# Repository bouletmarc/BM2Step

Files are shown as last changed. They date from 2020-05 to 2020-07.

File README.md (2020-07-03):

# BM2Step
Arduino based 2Step Launch Control Module similar to Bee*R for Honda/Acura

# Compatibility

- All Honda/Acura engines that are 4cylinder and running with a distributor (mainly SerieB, D, F and H engines).
- It does works on Automatics cars.

# Parts List
- 1x Arduino Nano V3 5V 16mhz atmega328p
- 1x 74HC00 Quad 2-input NAND gate (or 74LVC1G00 for a Single gate rather than a Quad gate)
- 2x 2N4401 transistors (2N2222/2N3904 can be used)
- 6x 1K Ohms resistors
- 1x 1 to 10 Ohm resistors (can be replaced with a jumper or '0ohm' directly but a resistor make the circuit safer!)
- 2x B10K Potentiometer 0931
- 2x 2mm to 5mm Leds
- 1x 7805/78M05 5v voltage regulator
- 2x 100nF capacitor (104)
- 1x Diode (minimum of 20v), can be 1N4002, 1N4004, 1N4148, etc..

# Installation

Inputs wires:
- ICM - Ignition Control Module signal from the ECU
- Potentiometer - Launch RPM selection
- Potentiometer - Cut RPM selection
- Activate Launch/2Step (sort to ground to activate)
- 12v Ignition On
- Ground

Outputs wires:
- ICM - Ignition Control Module singal Out for the distributor

**You don't need to power the arduino from the USB, the 7805/78M05 5v regulator output 5v from the 12v Ignition input wire to power the arduino when the Car ignition key are turned On!**

# How to use the BM2Step

1. Choose your desired Launch Control 2Step RPM with the potentiometer
2. Choose your desired Launch Control 2Step Cutting rpm windows with the potentiometer
3. Activate the Launch/2Step by sorting the Activate 'input' to the ground
4. Bring the engine RPM to the desired Launch Control 2Step RPM
5. Enjoy!

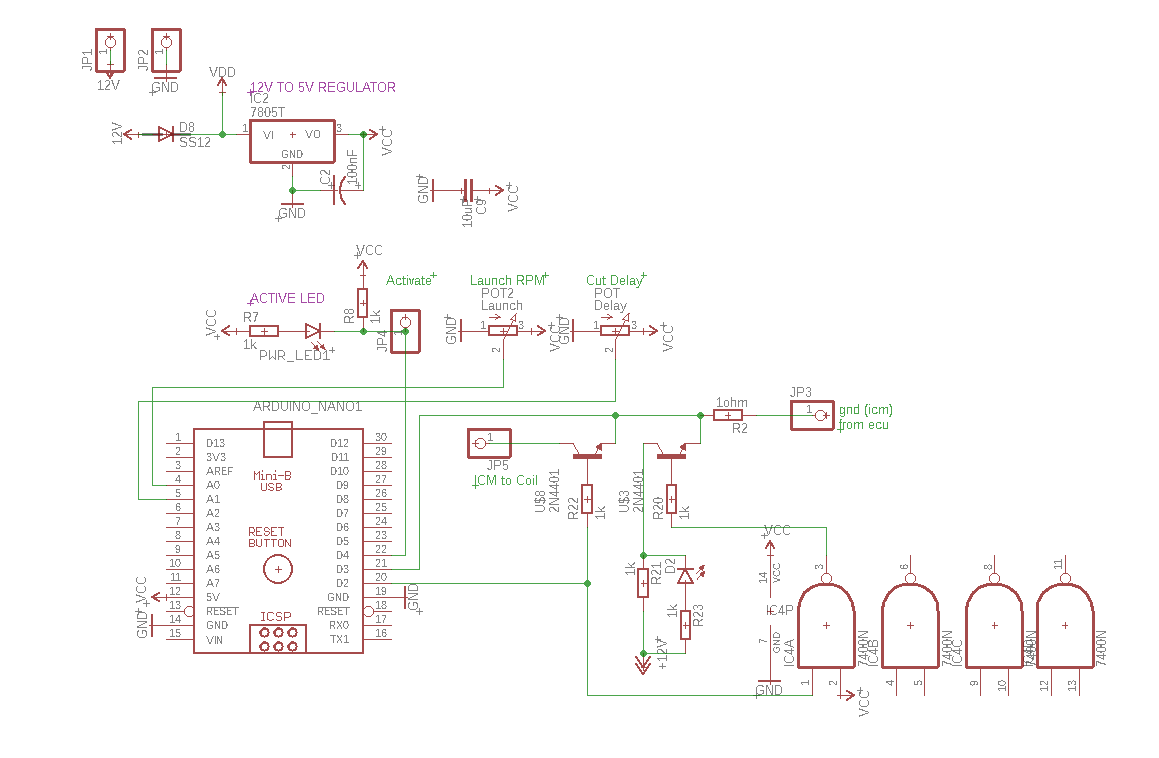
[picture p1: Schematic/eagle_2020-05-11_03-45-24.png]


# How the BM2Step works

The BM2Step works by disabling the ICM ouputs when the BM2Step are active and the engine rpm reach the Set RPM. The diagram have 2x 2n4401 transistors to control the direction of the ICM outputs. One transistor are sending the ICM signal back to the distributor (sending to the ICM ouputs on the BM2Step) while the other transistor are sending the ICM signal in a 'built-in distributor simulator'.

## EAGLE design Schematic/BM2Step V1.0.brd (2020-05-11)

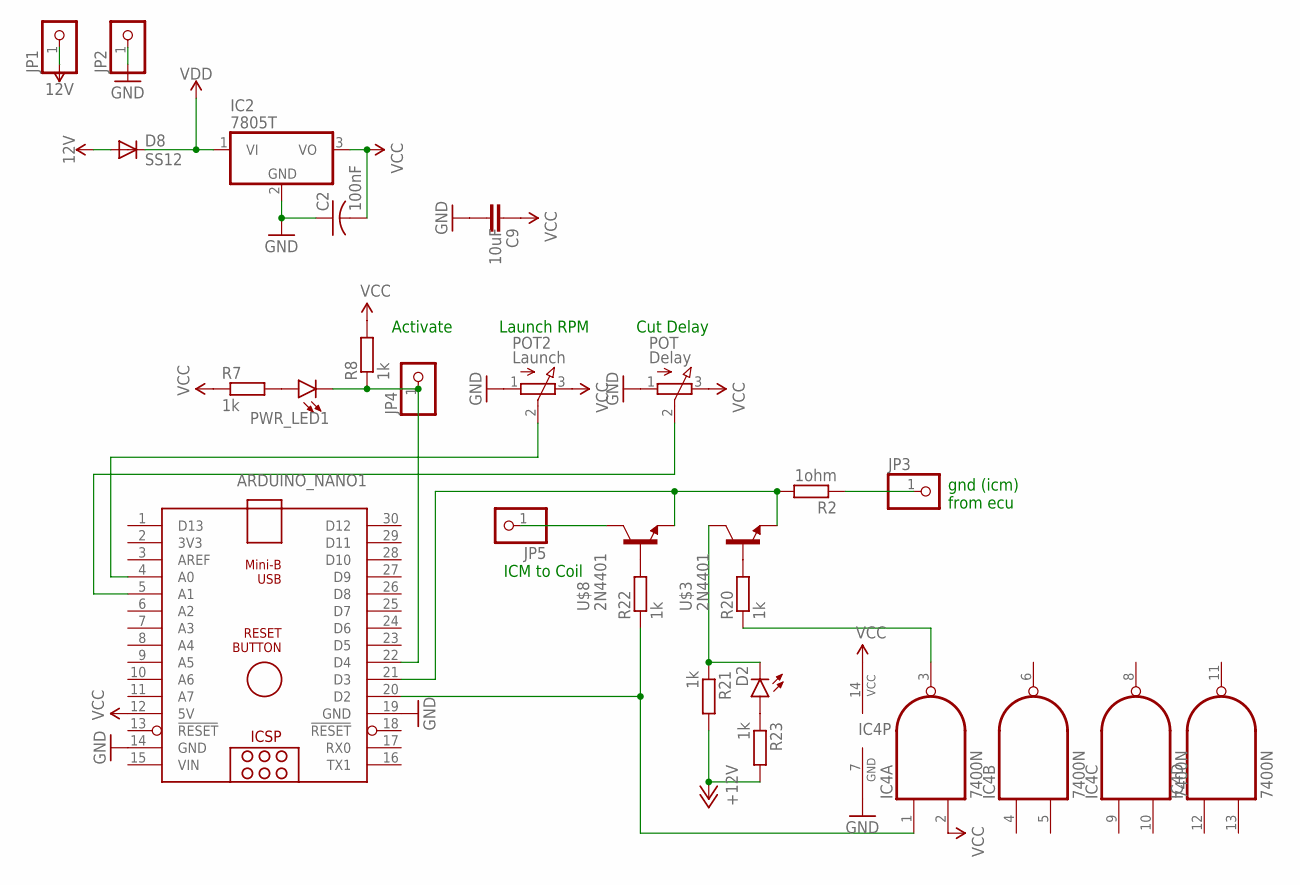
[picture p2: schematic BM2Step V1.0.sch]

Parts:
ARDUINO_NANO1: ARDUINO_NANO
C2: 100nF; C025-024X044
C9: 10uF; AXIAL-5MM
D2: LED3MM
D8: SS12; D-7.5
IC2: 7805T; TO220H
IC4: 7400N; DIL14
JP1, JP2, JP3, JP4, JP5: PINHD-1X1_LARGE; 1X01_LARGE
POT: Delay; EVUF
POT2: Launch; EVUF
PWR_LED1: LED3MM; LED_3MM
R2: 1ohm; 0204/7
R7, R8, R20, R21, R22, R23: 1k; 0204/7
U$3, U$8: 2N4401; TO92-ECB

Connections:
12V: D8.A, JP1.1
+12V: R21.2, R23.2
GND: ARDUINO_NANO1.14 (GND), ARDUINO_NANO1.19 (GND), C2.1, C9.P$2 (2), IC2.2 (GND), IC4.7 (GND), JP2.1, POT.1 (A), POT2.1 (A)
unnamed: IC4.3 (O), R20.1
unnamed: ARDUINO_NANO1.22 (D4), JP4.1, PWR_LED1.K (C), R8.1
unnamed: ARDUINO_NANO1.4 (A0), POT2.2 (S)
unnamed: ARDUINO_NANO1.5 (A1), POT.2 (S)
unnamed: JP3.1, R2.1
unnamed: ARDUINO_NANO1.21 (D3), R2.2, U$3.E, U$8.E
unnamed: PWR_LED1.A, R7.2
unnamed: R20.2, U$3.B
unnamed: D2.K (C), R21.1, U$3.C
unnamed: JP5.1, U$8.C
unnamed: R22.2, U$8.B
unnamed: ARDUINO_NANO1.20 (D2), IC4.1 (I0), R22.1
unnamed: D2.A, R23.1
VCC: ARDUINO_NANO1.12 (5V), C2.2, C9.P$1 (1), IC2.3 (VO), IC4.2 (I1), IC4.14 (VCC), POT.3 (E), POT2.3 (E), R7.1, R8.2
VDD: D8.C, IC2.1 (VI)
VIN: ARDUINO_NANO1.15 (VIN)

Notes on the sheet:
gnd (icm) from ecu
ICM to Coil
Launch RPM
Cut Delay
Activate

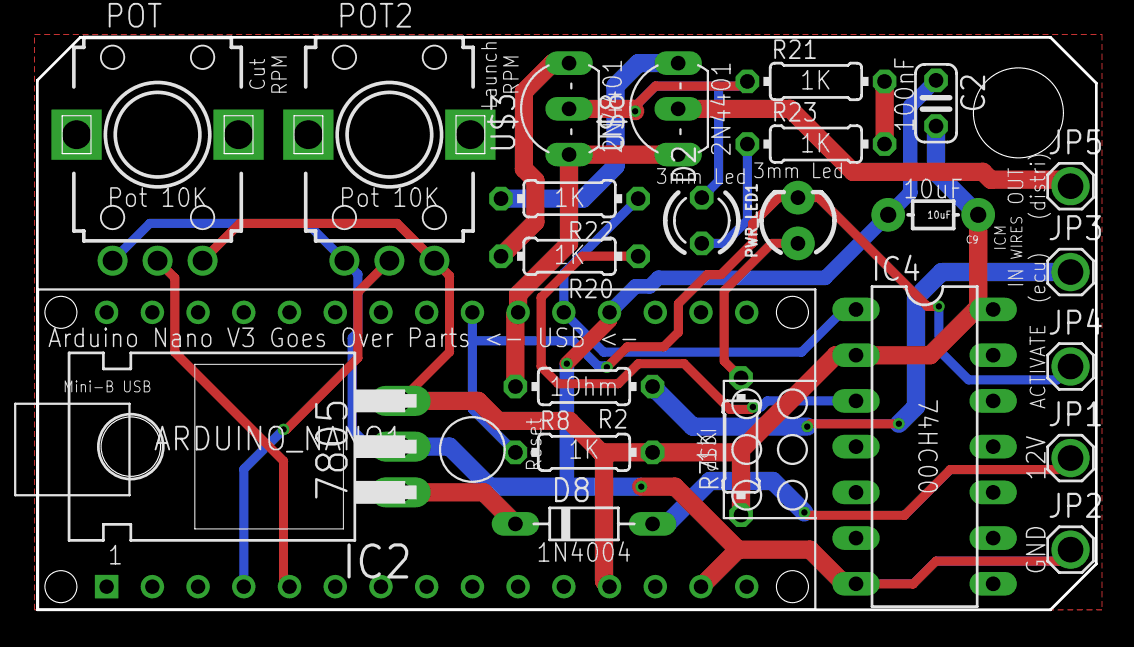
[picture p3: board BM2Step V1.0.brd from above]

Board: 2 copper layers, 58.8 x 31.8 mm, 24 parts (0 on the bottom side), 18 nets.

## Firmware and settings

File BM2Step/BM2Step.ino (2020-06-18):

#include <SPI.h>
#include <Wire.h>
#include "Arduino.h"

int ontime,offtime,duty;
float freq,period;

#define pulse_ip 3
#define Cutting_Output 2
#define Activate_Input 4
#define LaunchRPM_Input A0
#define LaunchDelay_Input A1

#define BAUDRATE  115200

int LaunchRPM = 3500;
int CutRPMWindows = 500;
int CurrentRPM = 0;
int SmoothRPM[] = {0, 0, 0};
int SmoothRPMBuffer[] = {0, 0, 0};
bool Cutting2Step = false;
int PotRpmValue;

void setup() {
  Serial.begin(BAUDRATE);
  
  pinMode(pulse_ip,INPUT);
  pinMode(Cutting_Output, OUTPUT);
  pinMode(LaunchRPM_Input, INPUT);
  pinMode(LaunchDelay_Input, INPUT);
  pinMode(Activate_Input, INPUT);
}

void loop() {
  ontime = pulseIn(pulse_ip,HIGH);
  offtime = pulseIn(pulse_ip,LOW);
  period = ontime+offtime;
  freq = 1000000.0/period;
  duty = (ontime/period)*100;

  if (duty > 0 && duty < 100) {
    CurrentRPM = freq * 30;
    AddToSmooth(CurrentRPM);
    
    GetLaunchRPM();
    GetCutRPM();
    Check2Step();
    
    SerialPrinting();
  }
  else {
    Disable2Step();
    Serial.print("Unknown RPM detected!");
    Serial.println("");
  }

  delay(1);

}

void GetLaunchRPM() {
  PotRpmValue = analogRead(LaunchRPM_Input);
  if (PotRpmValue>203)
  {
    LaunchRPM = map(PotRpmValue, 203, 1023, 4500, 9000);
  }
  else
  {
    if (PotRpmValue>126)
    {
      LaunchRPM = map(PotRpmValue, 127, 203, 3200, 4500);
    }
    else
    {
      LaunchRPM = map(PotRpmValue, 0, 126, 2500, 3200);
    }
  }
  LaunchRPM = (LaunchRPM +24)/25;
  LaunchRPM = LaunchRPM * 25;
}

void GetCutRPM() {
  CutRPMWindows = analogRead(LaunchDelay_Input);
}

void SerialPrinting() {
  Serial.print("Freq:");
  Serial.print(freq);
  Serial.print("Hz");
  
  Serial.print("\tDuty");
  Serial.print(duty);
  Serial.print("%");

  
  Serial.print("\tRPM:");
  Serial.print(GetSmoothRPM());
  //Serial.print(CurrentRPM);

  
  Serial.print("\t2Step:");
  Serial.print(Cutting2Step);
  Serial.print("\tLaunch:");
  Serial.print(LaunchRPM);
  Serial.print("\tCut:");
  Serial.print(CutRPMWindows);
  
  /*Serial.print("\ton");
  Serial.print(ontime);
  Serial.print("\toff");
  Serial.print(offtime);
  Serial.print("\ttime");
  Serial.print(period);*/
  
  Serial.println("");
}

void Check2Step() {
  bool CanLaunch = false;
  if (digitalRead(Activate_Input) == LOW) {
    CanLaunch = true;
  }

  if (CanLaunch) {
    if (GetSmoothRPM() > LaunchRPM && !Cutting2Step) {
    //if (CurrentRPM > LaunchRPM && !Cutting2Step) {
      Cutting2Step = true;
      digitalWrite(Cutting_Output, HIGH);
    }
    if (GetSmoothRPM() < LaunchRPM - CutRPMWindows && Cutting2Step) {
    //if (CurrentRPM < LaunchRPM - CutRPMWindows && Cutting2Step) {
      Cutting2Step = false;
      digitalWrite(Cutting_Output, LOW);
    }
  } else {
    Cutting2Step = false;
    digitalWrite(Cutting_Output, LOW);
  }
}

void Disable2Step() {
  
    Cutting2Step = false;
    digitalWrite(Cutting_Output, LOW);
}

void AddToSmooth(int AddThisRPM) {
  for (int i = 0; i < 3; i++) {
    SmoothRPMBuffer[i] = SmoothRPM[i];
  }

  SmoothRPM[0] = AddThisRPM;
  
  for (int i = 0; i < 2; i++) {
    SmoothRPM[i+1] = SmoothRPMBuffer[i];
  }
}

int GetSmoothRPM() {
  int TotalRPM = 0;
  for (int i = 0; i < 3; i++) {
    TotalRPM += SmoothRPM[i];
  }

  return TotalRPM / 3;
}

//#########################################################
//#########################################################
//#########################################################
//#########################################################


/*#define rpmPin 2
#define outputRPM 3
#define potPinDelay A0
#define potPinRPM1 A1
#define Activate 6

const int refreshRate = 10;

unsigned int cuttingDelay = 60;
unsigned int cuttingRPM1 = 6000;
unsigned int cuttingRPM2 = 4500;
volatile int revs = 0;
unsigned long rpm = 0;
unsigned long lastmillis = 0;
unsigned long lastmillisCutting = 0;
bool CuttingLimiter = false;
bool CanLaunch = false;


int SmoothSize = 50;
int SmoothingRPM[50];
int CurrentSmooth = 0;


void setup() {
  Serial.begin(115200);
   
  pinMode(Activate, INPUT);
  pinMode(rpmPin, INPUT);
  pinMode(outputRPM, OUTPUT);
  attachInterrupt(digitalPinToInterrupt(rpmPin), rpm_engine, FALLING);
}

void loop() {
  if (digitalRead(Activate) == LOW) {
    CanLaunch = true;
  }
  else {
    CanLaunch = false;
  }
  int potDelayRead = analogRead(potPinDelay);
  int potRPM1Read = analogRead(potPinRPM1);
  cuttingDelay = map(potDelayRead, 0, 1023, 0, 500);
  cuttingRPM1 = map(potRPM1Read, 0, 1023, 4000, 9000);
  
  if (millis() - lastmillis >= refreshRate) {
    //detachInterrupt(digitalPinToInterrupt(rpmPin)); // disable interrupt when calculating
    //rpm = (revs  *refreshRate);

    //CalcCutting();

    //SmoothingRPM[CurrentSmooth] = rpm;
    //if (CurrentSmooth < SmoothSize - 2) CurrentSmooth++;
    
    Serial.println("Cutting:" + String(CuttingLimiter) + ",\tRPM:" + String(rpm) + ",\tCut Delay:" + String(cuttingDelay) + ",\tCut RPM1:" + String(cuttingRPM1) + ",\tTest:" + String(revs));
    Serial.flush();     
     
    revs = 0; // restart the RPM counter
    lastmillis = millis(); // update lastmillis
    //attachInterrupt(digitalPinToInterrupt(rpmPin), rpm_engine, FALLING); // Enable interrupt
  }
}

int CalcSmoothRPM() {
  long AllRPM = 0;
   for (int i=0; i < SmoothSize; ++i ) {
    AllRPM += SmoothingRPM[i];
  }
  AllRPM = (AllRPM / SmoothSize);
  return (int) AllRPM;
}

void CalcCutting() {
  //Get Cutting
  if (CanLaunch) {
    if (CalcSmoothRPM() >= cuttingRPM1) {
      if (!CuttingLimiter) {
        CuttingLimiter = true;
        lastmillisCutting = millis();
      }
    }
    else {
      if (CuttingLimiter) {
        if (millis() - lastmillisCutting >= cuttingDelay) {
          CuttingLimiter = false;
        }
      }
    }
  }
  else {
    CuttingLimiter = false;
  }

  //Apply Cut
  if (CuttingLimiter) {
    digitalWrite(outputRPM, LOW);   
  }
  else {
    digitalWrite(outputRPM, HIGH);   
  }
}

void rpm_engine() {
  revs++; 
}*/

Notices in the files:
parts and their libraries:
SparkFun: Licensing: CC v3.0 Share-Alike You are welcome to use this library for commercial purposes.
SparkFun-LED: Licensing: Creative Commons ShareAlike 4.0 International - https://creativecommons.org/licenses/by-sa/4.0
